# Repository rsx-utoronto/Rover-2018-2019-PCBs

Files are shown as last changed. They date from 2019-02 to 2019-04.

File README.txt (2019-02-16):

PCB Repo:

1. Ensure when working, the forward / back annotation is allowed. (A bar in black and yellow stripes will appear at the top of the window if the annotation has broken)
2. Do not have two people working on a board at the same time - merging is hard. (At least until we figure out how to merge nicely)

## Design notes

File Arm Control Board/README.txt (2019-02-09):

Board and Schematic for the 2018-2019 Arm control Board

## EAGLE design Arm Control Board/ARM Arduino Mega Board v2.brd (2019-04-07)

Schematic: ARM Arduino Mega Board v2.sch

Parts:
ARDUINO_DUE1: ARDUINO_DUE_SHIELD
C1, C2: C-US050-045X075; C050-045X075
IC1: 7805TV; TO220V
JP1, JP2, JP3, JP4, JP5, JP12, JP13: PINHD-1X2; 1X02
LED1, LED2, LED3, LED4, LED5, LED6, LED7: LEDCHIP-LED0603; CHIP-LED0603
M-1, M-2, M-3, M-4, M-5, M-6, M-7: PINHD-1X8; 1X08
MD_OUT_1, MD_OUT_2, MD_OUT_3, MD_OUT_4, MD_OUT_5, MD_OUT_6, MD_OUT_7: PINHD-1X8; 1X08
R1, R2, R5, R6, R7, R8, R9, R12, R13, R14, R15, R16, R17, R18: 25K; R0603
R3, R4: 100K; R0603
S1, S2, S3, S4, S5, S6, S7: DS01E; DS-01
U$1: MEGA-FIT_RA_2
U$2: 14PINULTRAFIT
U$3: 4PIN_ULTRA_FIT

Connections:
3V3: ARDUINO_DUE1.3V3, S1.1, S2.1, S3.1, S4.1, S5.1, S6.1, S7.1
5V: ARDUINO_DUE1.5V0 (5V), R3.2, R4.2, U$3.PIN3
D0: ARDUINO_DUE1.0 (RX0<0), MD_OUT_7.2
D1: ARDUINO_DUE1.1 (TX0>1), MD_OUT_6.2
D2: ARDUINO_DUE1.2, MD_OUT_7.3
D3: ARDUINO_DUE1.3, MD_OUT_6.3
D4: ARDUINO_DUE1.4, MD_OUT_5.2
D5: ARDUINO_DUE1.5, MD_OUT_5.3
D6: ARDUINO_DUE1.6, MD_OUT_4.2
D7: ARDUINO_DUE1.7, MD_OUT_4.3
D8: ARDUINO_DUE1.8, MD_OUT_3.2
D9: ARDUINO_DUE1.9, MD_OUT_3.3
D10: ARDUINO_DUE1.10, MD_OUT_2.2
D11: ARDUINO_DUE1.11, MD_OUT_2.3
D12: ARDUINO_DUE1.12, MD_OUT_1.2
D13: ARDUINO_DUE1.13, MD_OUT_1.3
D14: ARDUINO_DUE1.14 (TX3_14)
D15: ARDUINO_DUE1.15 (RX3_15)
D22: ARDUINO_DUE1.22
D23: ARDUINO_DUE1.23
D24: ARDUINO_DUE1.24
D25: ARDUINO_DUE1.25
D26: ARDUINO_DUE1.26
D27: ARDUINO_DUE1.27
D28: ARDUINO_DUE1.28
D29: ARDUINO_DUE1.29
D30: ARDUINO_DUE1.30
D31: ARDUINO_DUE1.31
D32: ARDUINO_DUE1.32
D33: ARDUINO_DUE1.33
D34: ARDUINO_DUE1.34
D35: ARDUINO_DUE1.35
GND: ARDUINO_DUE1.GND, C1.2, C2.2, IC1.2 (GND), JP1.2, JP2.2, JP3.2, JP4.2, JP5.2, JP12.2, JP13.2, LED1.C, LED2.C, LED3.C, LED4.C, LED5.C, LED6.C, LED7.C, M-1.1, M-1.2, M-2.1, M-2.2, M-3.1, M-3.2, M-4.1, M-4.2, M-5.1, M-5.2, M-6.1, M-6.2, M-7.1, M-7.2, MD_OUT_1.1, MD_OUT_2.1, MD_OUT_3.1, MD_OUT_4.1, MD_OUT_5.1, MD_OUT_6.1, MD_OUT_7.1, R12.2, R13.2, R14.2, R15.2, R16.2, R17.2, R18.2, U$1.P$2, U$3.PIN1
N1: MD_OUT_2.4, R8.1, S6.2
N2: MD_OUT_3.4, R7.1, S5.2
N3: MD_OUT_4.4, R6.1, S4.2
N4: MD_OUT_5.4, R5.1, S3.2
N5: MD_OUT_6.4, R2.1, S2.2
N6: MD_OUT_7.4, R1.1, S1.2
N7: MD_OUT_1.4, R9.1, S7.2
unnamed: LED1.A, R1.2
unnamed: LED2.A, R2.2
unnamed: JP1.1, R12.1
unnamed: JP2.1, R13.1
unnamed: JP3.1, R14.1
unnamed: JP4.1, R15.1
unnamed: JP5.1, R16.1
unnamed: JP12.1, R17.1
unnamed: JP13.1, R18.1
unnamed: LED3.A, R5.2
unnamed: LED4.A, R6.2
unnamed: LED5.A, R7.2
unnamed: LED6.A, R8.2
unnamed: LED7.A, R9.2
OUTA1: M-1.5, M-1.6, U$2.PIN5
OUTA2: M-2.5, M-2.6, U$2.PIN1
OUTA3: M-3.5, M-3.6, U$2.PIN4
OUTA4: M-4.5, M-4.6, U$2.PIN8
OUTA5: M-5.5, M-5.6, U$2.PIN12
OUTA6: M-6.5, M-6.6, U$2.PIN13
OUTA7: M-7.5, M-7.6, U$2.PIN9
OUTB1: M-1.3, M-1.4, U$2.PIN7
OUTB2: M-2.3, M-2.4, U$2.PIN3
OUTB3: M-3.3, M-3.4, U$2.PIN2
OUTB4: M-4.3, M-4.4, U$2.PIN6
OUTB5: M-5.3, M-5.4, U$2.PIN10
OUTB6: M-6.3, M-6.4, U$2.PIN14
OUTB7: M-7.3, M-7.4, U$2.PIN11
SCL_OUT: ARDUINO_DUE1.21 (SCL_21), R3.1, U$3.PIN4
SDA_OUT: ARDUINO_DUE1.20 (SDA_20), R4.1, U$3.PIN2
V+: C2.1, IC1.1 (VI), M-1.7, M-1.8, M-2.7, M-2.8, M-3.7, M-3.8, M-4.7, M-4.8, M-5.7, M-5.8, M-6.7, M-6.8, M-7.7, M-7.8, U$1.P$1
VIN: ARDUINO_DUE1.VIN, C1.1, IC1.3 (VO)

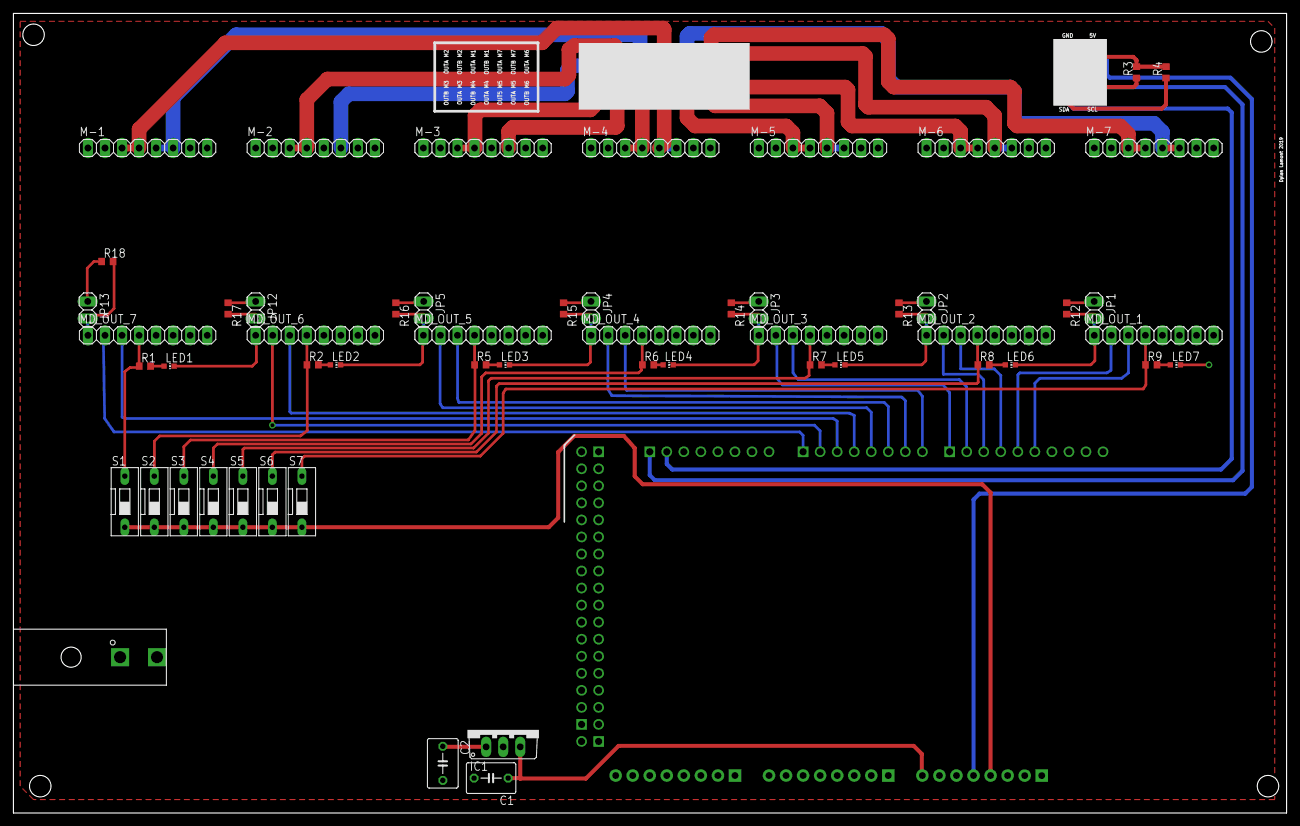
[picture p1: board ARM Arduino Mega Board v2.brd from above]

Board: 2 copper layers, 189.8 x 119.2 mm, 58 parts (1 on the bottom side), 56 nets.

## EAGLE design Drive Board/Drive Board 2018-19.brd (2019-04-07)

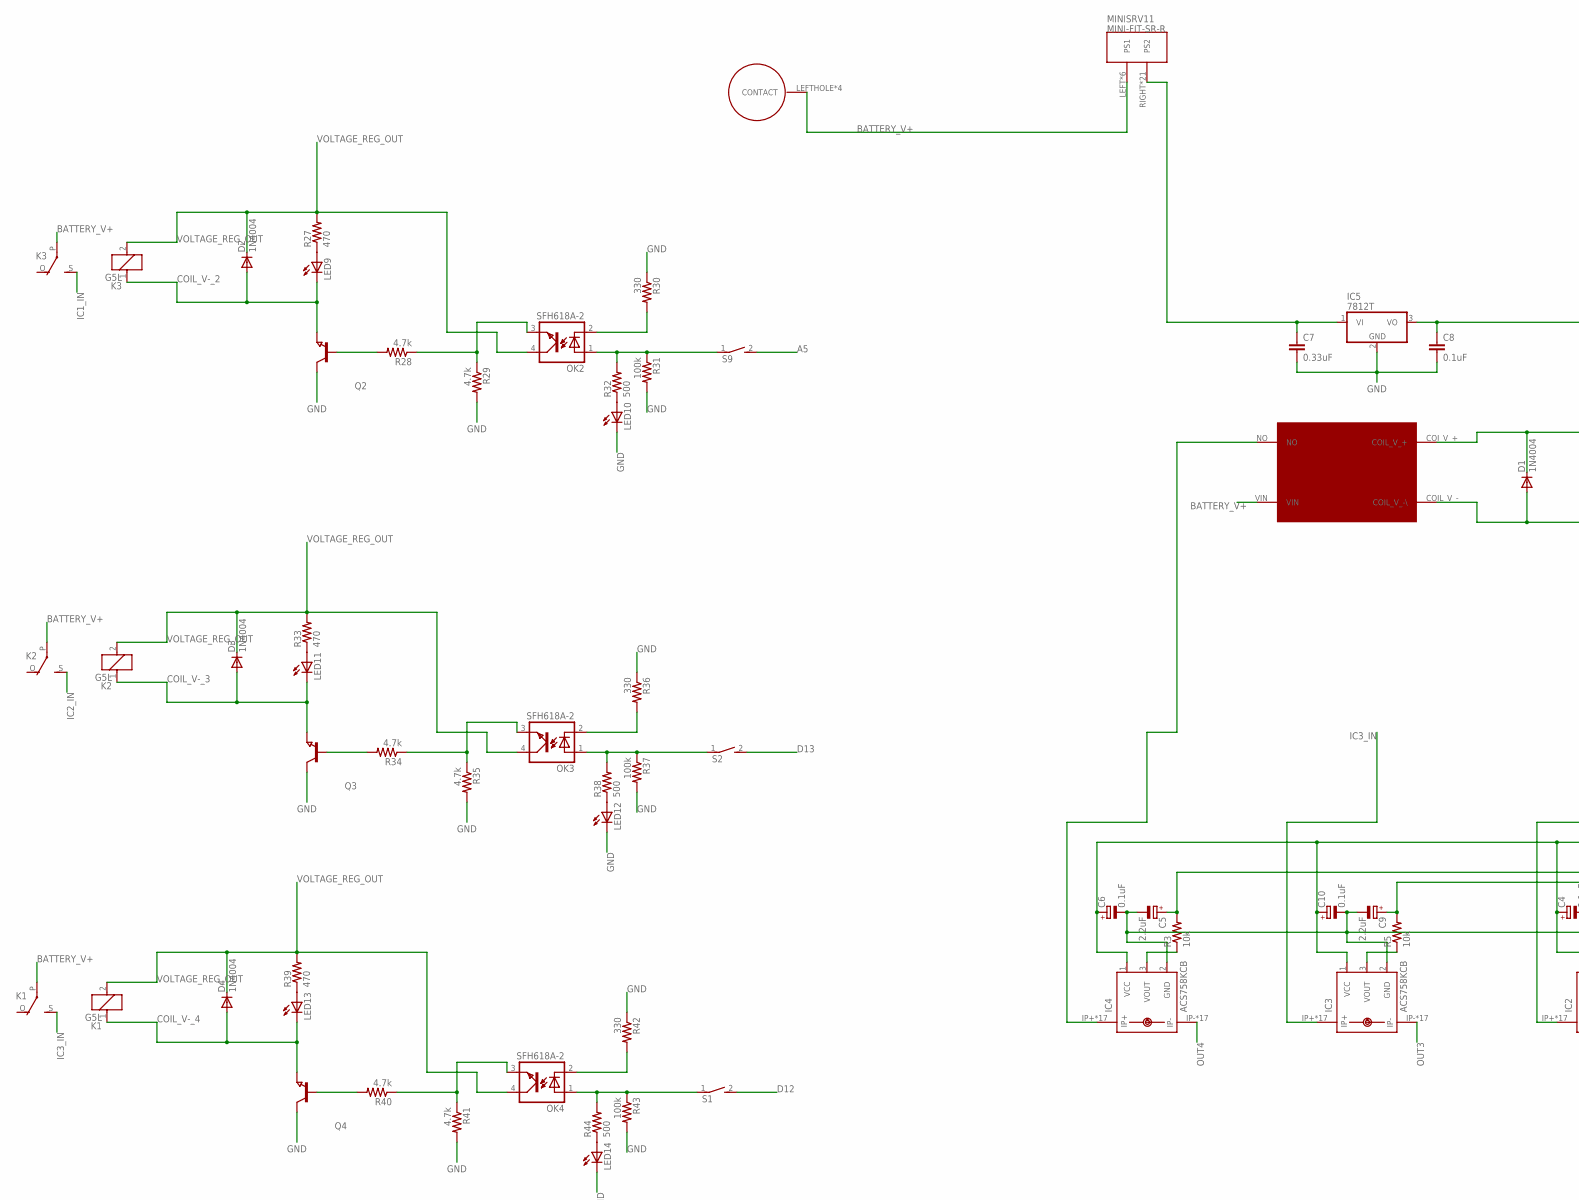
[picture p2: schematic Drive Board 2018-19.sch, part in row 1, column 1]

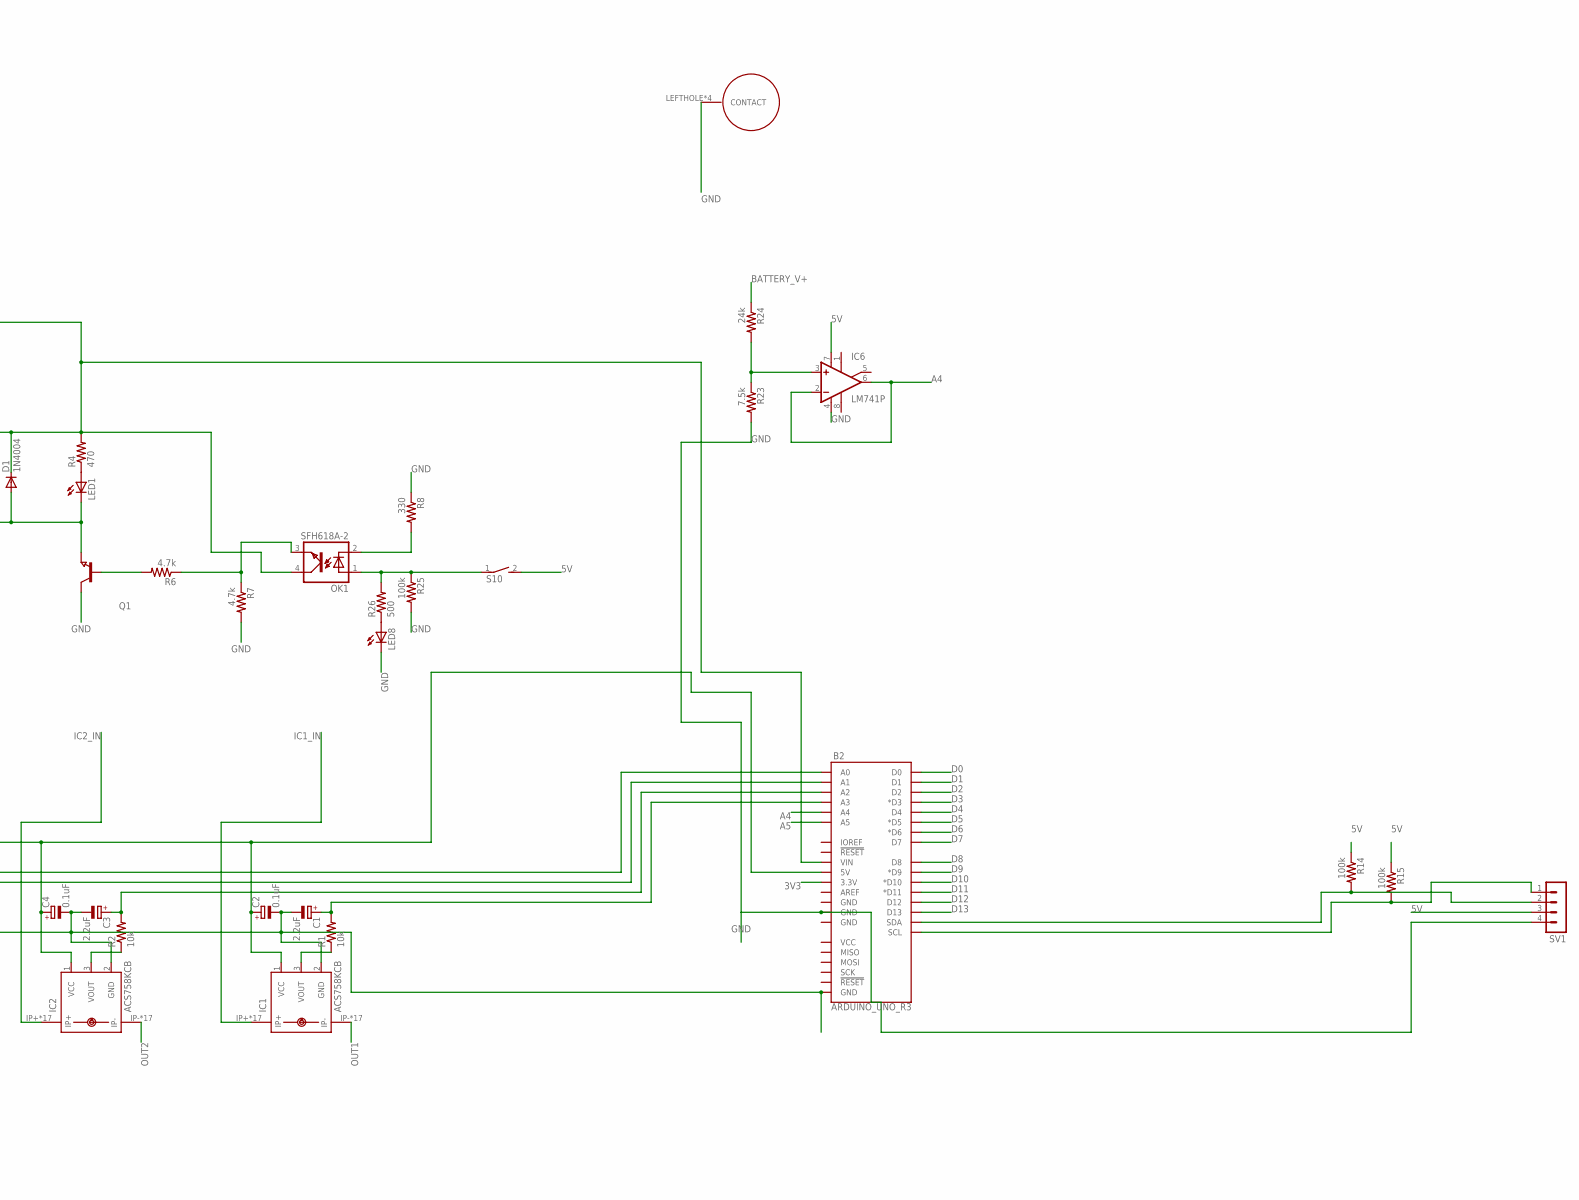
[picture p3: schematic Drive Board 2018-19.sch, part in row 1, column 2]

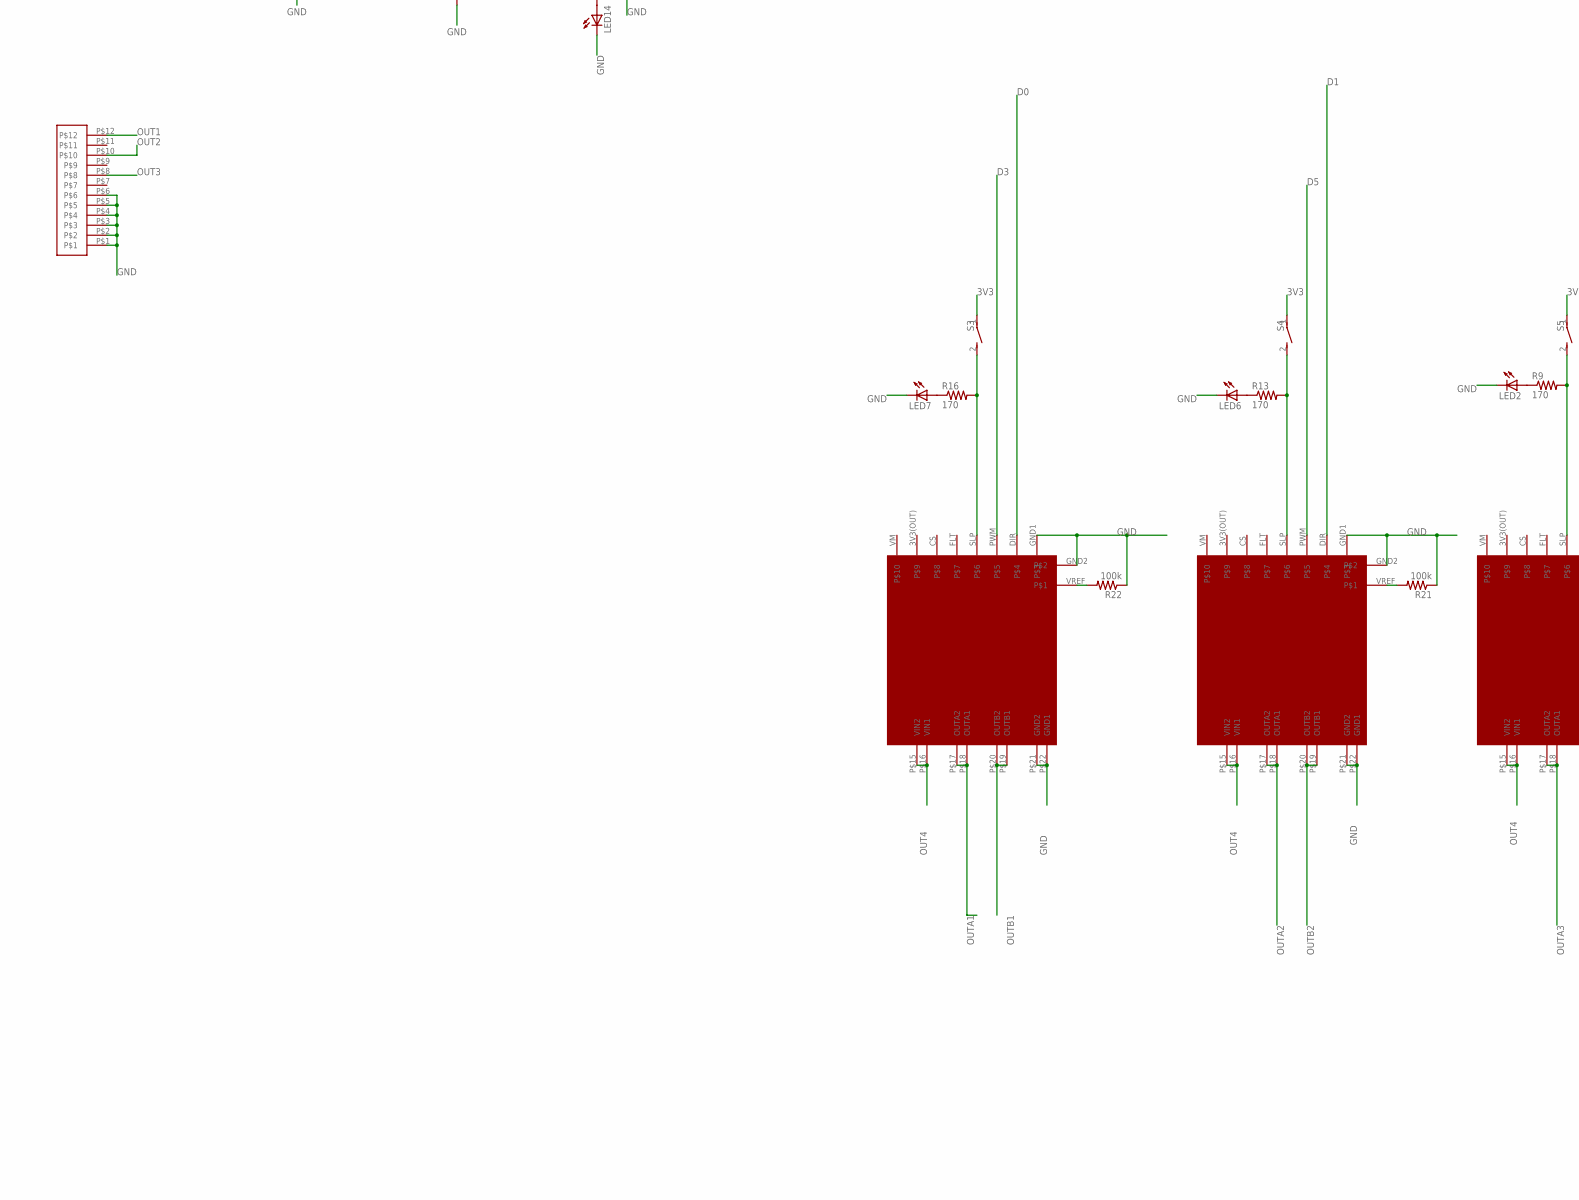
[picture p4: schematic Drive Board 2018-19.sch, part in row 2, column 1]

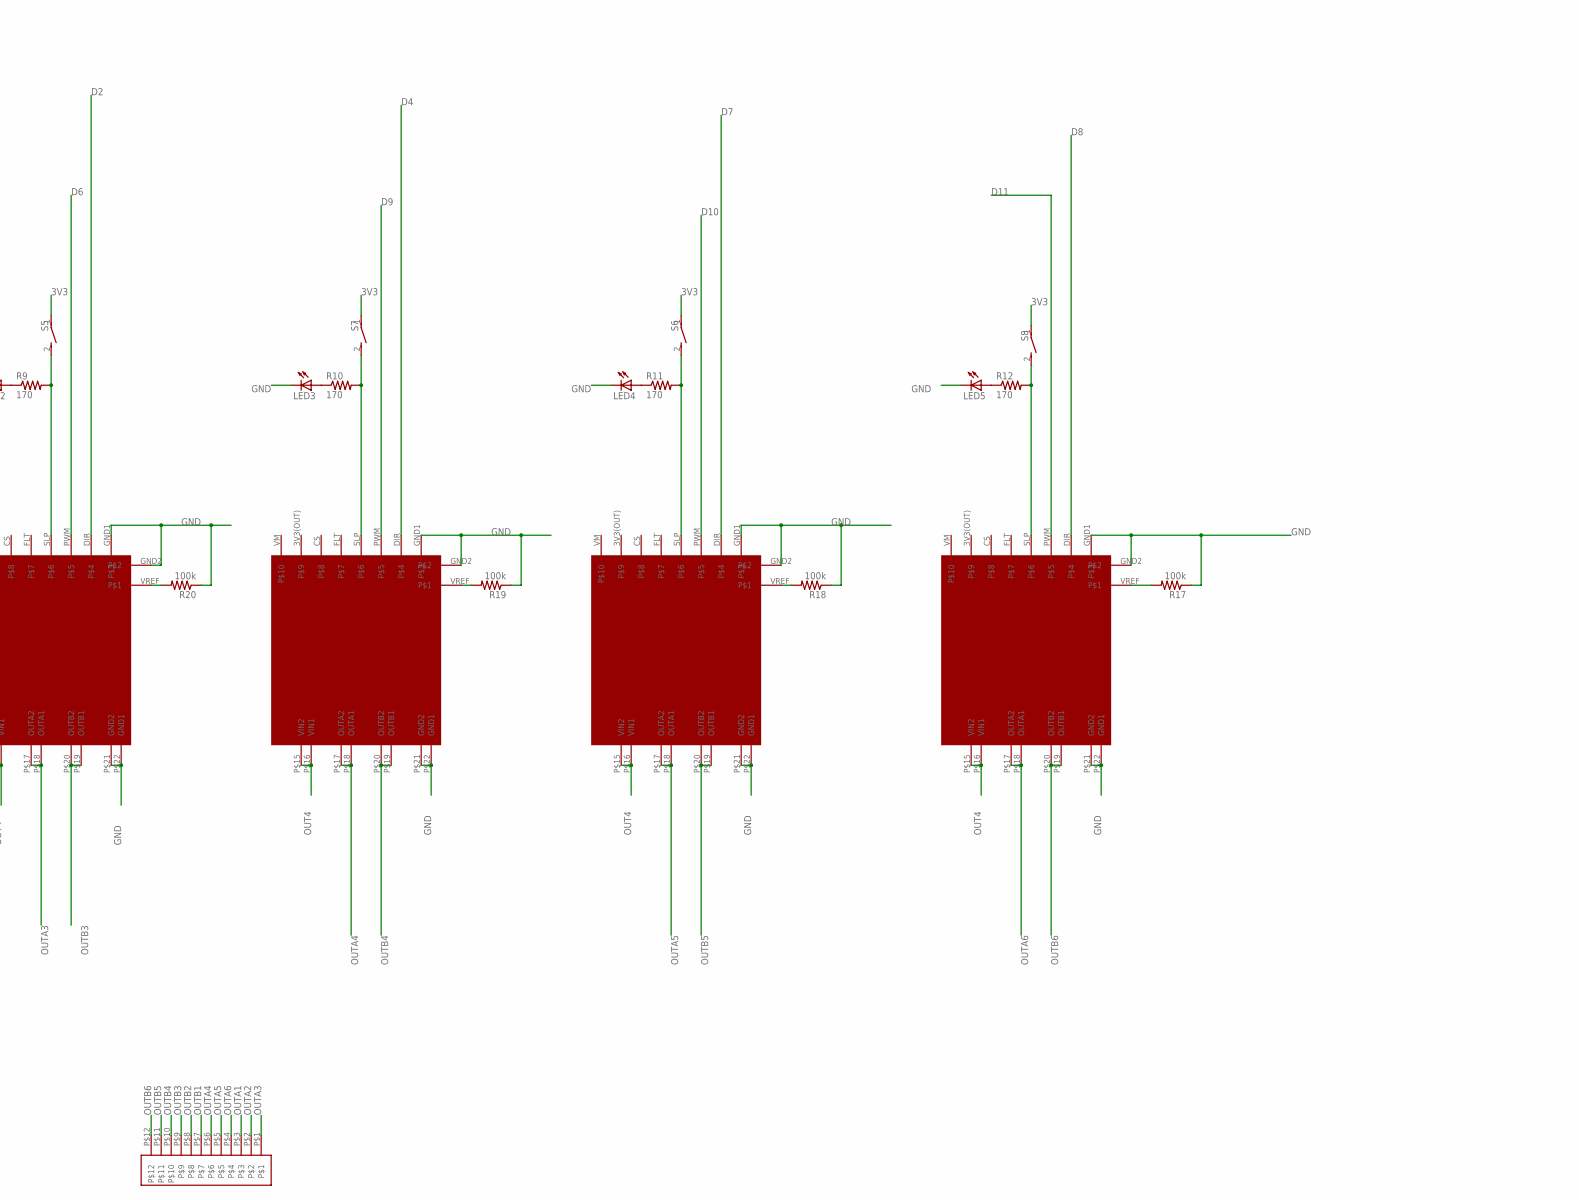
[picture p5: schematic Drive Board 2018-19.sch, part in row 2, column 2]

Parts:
B2: ARDUINO_UNO_R3; ARDUINO_R3
C1, C3, C5, C9: 2.2uF; E2,5-6
C2, C4, C6, C10: 0.1uF; E2,5-6
C7: 0.33uF; C5B5.5
C8: 0.1uF; C5B5.5
D1, D2, D3, D4: 1N4004; DO41-10
IC1, IC2, IC3, IC4: ACS758KCB; CB-PFF
IC5: 7812T; TO220H
IC6: LM741P; DIL08
K1, K2, K3: G5L; G5LE
LED1, LED2, LED3, LED4, LED5, LED6, LED7, LED8, LED9, LED10, LED11, LED12, LED13, LED14: LED_E; LED_1206
MINISRV11: MINI-FIT-SR-R
OK1, OK2, OK3, OK4: SFH618A-2; DIP4
Q1, Q2, Q3, Q4: NPN-TRANSISTOR_SOT23; SOT23
R1, R2, R3, R5: 10k; 0204/7
R4, R27, R33, R39: 470; 0207/10
R6, R7, R28, R29, R34, R35, R40, R41: 4.7k; 0207/10
R8, R30, R36, R42: 330; 0207/10
R9, R10, R11, R12, R13, R16: 170; 0207/10
R14, R15, R17, R18, R19, R20, R21, R22, R25, R31, R37, R43: 100k; 0207/10
R23: 7.5k; 0207/10
R24: 24k; 0207/10
R26, R32, R38, R44: 500; 0207/10
S1, S2, S3, S4, S5, S6, S7, S8, S9, S10: DS01E; DS-01
SV1: MA04-1
U$1, U$2, U$3, U$4, U$5, U$6: HPMD18V17
U$7, U$9: BUSBAR_MOUNT
U$11: JTN1AS-PA-F-DC12V
U$12, U$13: MEGA-FIT_RA_12

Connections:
3V3: B2.3.3V, S3.1, S4.1, S5.1, S6.1, S7.1, S8.1
5V: B2.5V, C2.+, C4.+, C6.+, C10.+, IC1.1 (VCC), IC2.1 (VCC), IC3.1 (VCC), IC4.1 (VCC), IC6.7 (V+), R14.1, R15.1, S10.2, SV1.3
A4: B2.A4, IC6.2 (-IN), IC6.6 (OUT)
A5: B2.A5, S9.2
BATTERY_V+: K1.P, K2.P, K3.P, MINISRV11.LEFT (PS1), MINISRV11.LEFT@1 (PS1), MINISRV11.LEFT@2 (PS1), MINISRV11.LEFT@3 (PS1), MINISRV11.LEFT@4 (PS1), MINISRV11.LEFT@5 (PS1), R24.1, U$7.LEFTHOLE, U$7.P$1, U$7.P$2, U$7.RIGHTHOLE, U$11.VIN
COIL_V-_1: D1.A, LED1.C, Q1.2 (E), U$11.COIL_V_- (COIL_V_-\)
COIL_V-_2: D2.A, K3.1, LED9.C, Q2.2 (E)
COIL_V-_3: D3.A, K2.1, LED11.C, Q3.2 (E)
COIL_V-_4: D4.A, K1.1, LED13.C, Q4.2 (E)
D0: B2.D0, U$1.DIR
D1: B2.D1, U$2.DIR
D2: B2.D2, U$3.DIR
D3: B2.D3 (*D3), U$1.PWM
D4: B2.D4, U$4.DIR
D5: B2.D5 (*D5), U$2.PWM
D6: B2.D6 (*D6), U$3.PWM
D7: B2.D7, U$5.DIR
D8: B2.D8, U$6.DIR
D9: B2.D9 (*D9), U$4.PWM
D10: B2.D10 (*D10), U$5.PWM
D11: B2.D11 (*D11), U$6.PWM
D12: B2.D12, S1.2
D13: B2.D13, S2.2
ESTOP: C7.1, IC5.1 (VI), MINISRV11.RIGHT (PS2), MINISRV11.RIGHT@1 (PS2), MINISRV11.RIGHT@2 (PS2), MINISRV11.RIGHT@3 (PS2), MINISRV11.RIGHT@4 (PS2), MINISRV11.RIGHT@5 (PS2), MINISRV11.RIGHT@6 (PS2), MINISRV11.RIGHT@7 (PS2), MINISRV11.RIGHT@8 (PS2), MINISRV11.RIGHT@9 (PS2), MINISRV11.RIGHT@10 (PS2), MINISRV11.RIGHT@11 (PS2), MINISRV11.RIGHT@12 (PS2), MINISRV11.RIGHT@13 (PS2), MINISRV11.RIGHT@14 (PS2), MINISRV11.RIGHT@15 (PS2), MINISRV11.RIGHT@16 (PS2), MINISRV11.RIGHT@17 (PS2), MINISRV11.RIGHT@18 (PS2), MINISRV11.RIGHT@19 (PS2), MINISRV11.RIGHT@20 (PS2)
GND: B2.GND@1 (GND), B2.GND@3 (GND), C1.-, C2.-, C3.-, C4.-, C5.-, C6.-, C7.2, C8.2, C9.-, C10.-, IC1.2 (GND), IC2.2 (GND), IC3.2 (GND), IC4.2 (GND), IC5.2 (GND), IC6.4 (V-), LED2.C, LED3.C, LED4.C, LED5.C, LED6.C, LED7.C, LED8.C, LED10.C, LED12.C, LED14.C, Q1.3 (C), Q2.3 (C), Q3.3 (C), Q4.3 (C), R7.2, R8.1, R17.1, R18.1, R19.1, R20.1, R21.1, R22.1, R23.2, R25.2, R29.2, R30.1, R31.2, R35.2, R36.1, R37.2, R41.2, R42.1, R43.2, SV1.4, U$1.GND1, U$1.GND2, U$1.P$21 (GND2), U$1.P$22 (GND1), U$2.GND1, U$2.GND2, U$2.P$21 (GND2), U$2.P$22 (GND1), U$3.GND1, U$3.GND2, U$3.P$21 (GND2), U$3.P$22 (GND1), U$4.GND1, U$4.GND2, U$4.P$21 (GND2), U$4.P$22 (GND1), U$5.GND1, U$5.GND2, U$5.P$21 (GND2), U$5.P$22 (GND1), U$6.GND1, U$6.GND2, U$6.P$21 (GND2), U$6.P$22 (GND1), U$9.LEFTHOLE, U$9.P$1, U$9.P$2, U$9.RIGHTHOLE, U$13.P$1, U$13.P$2, U$13.P$3, U$13.P$4, U$13.P$5, U$13.P$6
IC1_IN: IC1.IP+, IC1.IP+@2 (IP+), IC1.IP+@3 (IP+), IC1.IP+@4 (IP+), IC1.IP+@5 (IP+), IC1.IP+@6 (IP+), IC1.IP+@7 (IP+), IC1.IP+@8 (IP+), IC1.IP+@9 (IP+), IC1.IP+@10 (IP+), IC1.IP+@11 (IP+), IC1.IP+@12 (IP+), IC1.IP+@13 (IP+), IC1.IP+@14 (IP+), IC1.IP+@15 (IP+), IC1.IP+@16 (IP+), IC1.IP+@17 (IP+), K3.S
IC2_IN: IC2.IP+, IC2.IP+@2 (IP+), IC2.IP+@3 (IP+), IC2.IP+@4 (IP+), IC2.IP+@5 (IP+), IC2.IP+@6 (IP+), IC2.IP+@7 (IP+), IC2.IP+@8 (IP+), IC2.IP+@9 (IP+), IC2.IP+@10 (IP+), IC2.IP+@11 (IP+), IC2.IP+@12 (IP+), IC2.IP+@13 (IP+), IC2.IP+@14 (IP+), IC2.IP+@15 (IP+), IC2.IP+@16 (IP+), IC2.IP+@17 (IP+), K2.S
IC3_IN: IC3.IP+, IC3.IP+@2 (IP+), IC3.IP+@3 (IP+), IC3.IP+@4 (IP+), IC3.IP+@5 (IP+), IC3.IP+@6 (IP+), IC3.IP+@7 (IP+), IC3.IP+@8 (IP+), IC3.IP+@9 (IP+), IC3.IP+@10 (IP+), IC3.IP+@11 (IP+), IC3.IP+@12 (IP+), IC3.IP+@13 (IP+), IC3.IP+@14 (IP+), IC3.IP+@15 (IP+), IC3.IP+@16 (IP+), IC3.IP+@17 (IP+), K1.S
unnamed: LED8.A, R26.1
unnamed: IC1.3 (VOUT), R1.1
unnamed: LED1.A, R4.1
unnamed: B2.A3, C1.+, R1.2
unnamed: IC6.3 (+IN), R23.1, R24.2
unnamed: IC2.3 (VOUT), R2.1
unnamed: LED9.A, R27.1
unnamed: B2.A2, C3.+, R2.2
unnamed: Q2.1 (B), R28.2
unnamed: IC4.3 (VOUT), R3.1
unnamed: OK2.3 (EMIT), R28.1, R29.1
unnamed: OK2.2 (C), R30.2
unnamed: B2.A1, C9.+, R5.2
unnamed: LED10.A, R32.1
unnamed: LED11.A, R33.1
unnamed: Q1.1 (B), R6.2
unnamed: IC3.3 (VOUT), R5.1
unnamed: Q3.1 (B), R34.2
unnamed: B2.A0, C5.+, R3.2
unnamed: OK3.3 (EMIT), R34.1, R35.1
unnamed: OK1.3 (EMIT), R6.1, R7.1
unnamed: OK3.2 (C), R36.2
unnamed: LED12.A, R38.1
unnamed: IC4.IP+, IC4.IP+@2 (IP+), IC4.IP+@3 (IP+), IC4.IP+@4 (IP+), IC4.IP+@5 (IP+), IC4.IP+@6 (IP+), IC4.IP+@7 (IP+), IC4.IP+@8 (IP+), IC4.IP+@9 (IP+), IC4.IP+@10 (IP+), IC4.IP+@11 (IP+), IC4.IP+@12 (IP+), IC4.IP+@13 (IP+), IC4.IP+@14 (IP+), IC4.IP+@15 (IP+), IC4.IP+@16 (IP+), IC4.IP+@17 (IP+), U$11.NO
unnamed: LED13.A, R39.1
unnamed: Q4.1 (B), R40.2
unnamed: OK4.3 (EMIT), R40.1, R41.1
unnamed: OK4.2 (C), R42.2
unnamed: LED14.A, R44.1
unnamed: OK1.2 (C), R8.2
unnamed: R18.2, U$5.VREF
unnamed: R20.2, U$3.VREF
unnamed: LED2.A, R9.1
unnamed: R17.2, U$6.VREF
unnamed: B2.SCL, R15.2, SV1.1
unnamed: B2.SDA, R14.2, SV1.2
unnamed: LED3.A, R10.1
unnamed: LED4.A, R11.1
unnamed: LED5.A, R12.1
unnamed: R19.2, U$4.VREF
unnamed: LED6.A, R13.1
unnamed: LED7.A, R16.1
unnamed: R21.2, U$2.VREF
unnamed: R22.2, U$1.VREF
unnamed: R12.2, S8.2, U$6.SLP
unnamed: R11.2, S6.2, U$5.SLP
unnamed: R10.2, S7.2, U$4.SLP
unnamed: R9.2, S5.2, U$3.SLP
unnamed: R13.2, S4.2, U$2.SLP
unnamed: R16.2, S3.2, U$1.SLP
OPTO1: OK2.1 (A), R31.1, R32.2, S9.1
OPTO2: OK3.1 (A), R37.1, R38.2, S2.1
OPTO3: OK4.1 (A), R43.1, R44.2, S1.1
OPTO4: OK1.1 (A), R25.1, R26.2, S10.1
OUT1: IC1.IP-, IC1.IP-@2 (IP-), IC1.IP-@3 (IP-), IC1.IP-@4 (IP-), IC1.IP-@5 (IP-), IC1.IP-@6 (IP-), IC1.IP-@7 (IP-), IC1.IP-@8 (IP-), IC1.IP-@9 (IP-), IC1.IP-@10 (IP-), IC1.IP-@11 (IP-), IC1.IP-@12 (IP-), IC1.IP-@13 (IP-), IC1.IP-@14 (IP-), IC1.IP-@15 (IP-), IC1.IP-@16 (IP-), IC1.IP-@17 (IP-), U$13.P$12
OUT2: IC2.IP-, IC2.IP-@2 (IP-), IC2.IP-@3 (IP-), IC2.IP-@4 (IP-), IC2.IP-@5 (IP-), IC2.IP-@6 (IP-), IC2.IP-@7 (IP-), IC2.IP-@8 (IP-), IC2.IP-@9 (IP-), IC2.IP-@10 (IP-), IC2.IP-@11 (IP-), IC2.IP-@12 (IP-), IC2.IP-@13 (IP-), IC2.IP-@14 (IP-), IC2.IP-@15 (IP-), IC2.IP-@16 (IP-), IC2.IP-@17 (IP-), U$13.P$10
OUT3: IC3.IP-, IC3.IP-@2 (IP-), IC3.IP-@3 (IP-), IC3.IP-@4 (IP-), IC3.IP-@5 (IP-), IC3.IP-@6 (IP-), IC3.IP-@7 (IP-), IC3.IP-@8 (IP-), IC3.IP-@9 (IP-), IC3.IP-@10 (IP-), IC3.IP-@11 (IP-), IC3.IP-@12 (IP-), IC3.IP-@13 (IP-), IC3.IP-@14 (IP-), IC3.IP-@15 (IP-), IC3.IP-@16 (IP-), IC3.IP-@17 (IP-), U$13.P$8
OUT4: IC4.IP-, IC4.IP-@2 (IP-), IC4.IP-@3 (IP-), IC4.IP-@4 (IP-), IC4.IP-@5 (IP-), IC4.IP-@6 (IP-), IC4.IP-@7 (IP-), IC4.IP-@8 (IP-), IC4.IP-@9 (IP-), IC4.IP-@10 (IP-), IC4.IP-@11 (IP-), IC4.IP-@12 (IP-), IC4.IP-@13 (IP-), IC4.IP-@14 (IP-), IC4.IP-@15 (IP-), IC4.IP-@16 (IP-), IC4.IP-@17 (IP-), U$1.P$15 (VIN2), U$1.P$16 (VIN1), U$2.P$15 (VIN2), U$2.P$16 (VIN1), U$3.P$15 (VIN2), U$3.P$16 (VIN1), U$4.P$15 (VIN2), U$4.P$16 (VIN1), U$5.P$15 (VIN2), U$5.P$16 (VIN1), U$6.P$15 (VIN2), U$6.P$16 (VIN1)
OUTA1: U$1.P$17 (OUTA2), U$1.P$18 (OUTA1), U$12.P$3
OUTA2: U$2.P$17 (OUTA2), U$2.P$18 (OUTA1), U$12.P$2
OUTA3: U$3.P$17 (OUTA2), U$3.P$18 (OUTA1), U$12.P$1
OUTA4: U$4.P$17 (OUTA2), U$4.P$18 (OUTA1), U$12.P$6
OUTA5: U$5.P$17 (OUTA2), U$5.P$18 (OUTA1), U$12.P$5
OUTA6: U$6.P$17 (OUTA2), U$6.P$18 (OUTA1), U$12.P$4
OUTB1: U$1.P$19 (OUTB1), U$1.P$20 (OUTB2), U$12.P$7
OUTB2: U$2.P$19 (OUTB1), U$2.P$20 (OUTB2), U$12.P$8
OUTB3: U$3.P$19 (OUTB1), U$3.P$20 (OUTB2), U$12.P$9
OUTB4: U$4.P$19 (OUTB1), U$4.P$20 (OUTB2), U$12.P$10
OUTB5: U$5.P$19 (OUTB1), U$5.P$20 (OUTB2), U$12.P$11
OUTB6: U$6.P$19 (OUTB1), U$6.P$20 (OUTB2), U$12.P$12
VOLTAGE_REG_OUT: B2.VIN, C8.1, D1.C, D2.C, D3.C, D4.C, IC5.3 (VO), K1.2, K2.2, K3.2, OK1.4 (COL), OK2.4 (COL), OK3.4 (COL), OK4.4 (COL), R4.2, R27.2, R33.2, R39.2, U$11.COI_V_+ (COIL_V_+)

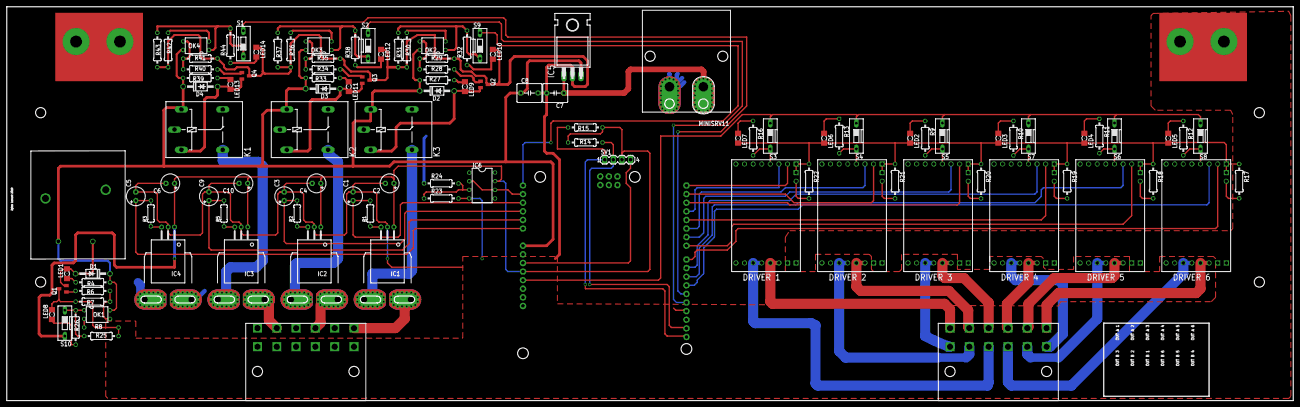
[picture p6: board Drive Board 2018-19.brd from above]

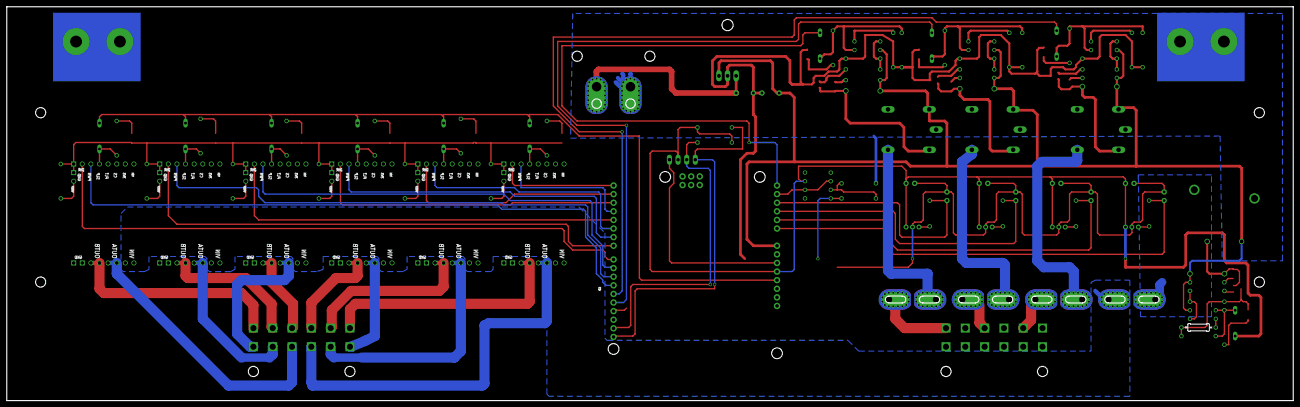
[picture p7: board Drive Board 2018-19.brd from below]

Board: 2 copper layers, 379.8 x 116.3 mm, 113 parts (2 on the bottom side), 99 nets.

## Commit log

2019-02-09 Set up Arm Control Board Folder
2019-02-09 Changed board to Mega
    [Arm Board Rev 1.0.brd, Arm Board Rev 1.0.sch]
2019-02-09 added pull up resistors for i2c
    [Arm Board Rev 1.0.sch]
2019-02-09 removed tx and rx
    [Arm Board Rev 1.0.brd, Arm Board Rev 1.0.sch]
2019-02-09 Placed power connector
2019-02-09 trying to fix conflict
    [Arm Board Rev 1.0.sch]
2019-02-09 fixing conflict
    [Arm Board Rev 1.0.brd, Arm Board Rev 1.0.sch]
2019-02-09 still trying to fix
    [Arm Board Rev 1.0.brd, Arm Board Rev 1.0.sch]
2019-02-09 this should be fixed
    [Arm Board Rev 1.0.brd, Arm Board Rev 1.0.sch]
2019-02-16 Added Drive Boards
    [Drive Board 2018-19.brd, Drive Board 2018-19.sch]
2019-02-20 deleted old components
    need to change footprint of relay
2019-02-20 Begin prep for new board
2019-02-21 Motor drivers added
    [Drive Board 2018-19.brd, Drive Board 2018-19.sch]
2019-02-22 Added Busbar lbr and other power connections to sch
    [Drive Board 2018-19.brd]
2019-02-23 Started board routing
    [Drive Board 2018-19.brd, Drive Board 2018-19.sch]
2019-02-24 first attempt finished for board design
    [Drive Board 2018-19.brd, Drive Board 2018-19.sch]
2019-03-02 Re doing layout, just need planes
    [Drive Board 2018-19.brd, Drive Board 2018-19.sch]
2019-03-02 Finished First draft
    [Drive Board 2018-19.sch]
2019-03-06 Fixed optocoupler mismatched pins
    [Drive Board 2018-19.brd, Drive Board 2018-19.sch]
2019-03-10 Update from chris meeting
    [Drive Board 2018-19.brd, Drive Board 2018-19.sch]
2019-03-11 Change to t aand bstop layers of the bus bar termials
    [Drive Board 2018-19.brd, Drive Board 2018-19.sch]
2019-03-11 Fixed Battery terminal pad connection
    [Drive Board 2018-19.brd, Drive Board 2018-19.sch]
2019-03-11 Fixed overlap of trace for current sensor
    [Drive Board 2018-19.brd]
2019-03-11 fixed mixed ground network
    [Drive Board 2018-19.brd, Drive Board 2018-19.sch]
2019-03-16 Arm control Board: mirrored arduino, added switches, added mega fit for power, added motor indicator LEDs, added LM7805 for Arduino power regulation
    [ARM Arduino Mega Board.brd, ARM Arduino Mega Board.sch, Arm Board Rev 1.0.brd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]
2019-03-16 Updated the path for the voltage regulator
2019-03-22 Added Components for relay
    [Drive Board 2018-19.brd, Drive Board 2018-19.sch]
2019-03-23 Finished Layout for Relay support circuitry
    [ARM Arduino Mega Board.brd, ARM Arduino Mega Board.sch, Drive Board 2018-19.brd]
2019-03-25 Relay control from DIO pins implemented
    [Drive Board 2018-19.brd, Drive Board 2018-19.sch]
2019-03-27 Added ultrafit connectors
    [ARM Arduino Mega Board v2.brd, ARM Arduino Mega Board v2.sch]
2019-03-27 updated naming scheme
    [ARM Arduino Mega Board.brd, ARM Arduino Mega Board.sch]
2019-03-28 Updated trace width and added connector information
    [Drive Board 2018-19.brd]
2019-03-28 Updated Vin plane
    [Drive Board 2018-19.brd]
2019-03-28 Pin Map for Arm Board
2019-04-07 updated plane thickness
    [ARM Arduino Mega Board v2.brd, Drive Board 2018-19.brd]
2019-04-07 Gerbers added for drive board and arm control pcb
    [ARM Arduino Mega Board v2.brd, Drive Board 2018-19.brd]

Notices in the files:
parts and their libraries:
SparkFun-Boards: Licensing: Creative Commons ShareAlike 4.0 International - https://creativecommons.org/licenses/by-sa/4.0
